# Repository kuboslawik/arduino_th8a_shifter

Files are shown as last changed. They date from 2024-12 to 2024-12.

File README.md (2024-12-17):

# Arduino TH8A Shifter Mod
Revive broken Thrustmaster TH8A shifter using Arduino and 3-axis magnetometer TLV493D module.

## Requirements
 - Arduino with USB HID capabilites, for this project Pro Micro is best suited due to small footprint
 - 3-axis magnetometer TLV493D
 - 3D printer to print custom Arduino mount
 - 4 threading screws to mount magnetometer

## Wiring
Wiring between TLV493D and Ardunio:
 - Vin -> VCC
 - GND -> GND
 - SCL -> pin 3 (SCL)
 - SDA -> pin 2 (SDA)

Wiring between TH8A pushbutton and Arduino:
 - One end should be connected to ground, and the other to pin 15 configured as pull-up.

## Code
Depending on your module, polar and azimuth values might differ, because of this, between lines 95 and 100 there is commented code which you can use to find perfect values and modify gears mapping accordingly.

For compatibility with older games, shifter gears are registerd as keyboard inputs, not as game controller buttons. Gears are coresponding to 1-8 keys in H-mode, and to +/- signs in sequential mode.

## STL Model
To mount Arduino and magnetometer, we need to print custom mount, located in 'assets/stl_part.stl' folder in repo.

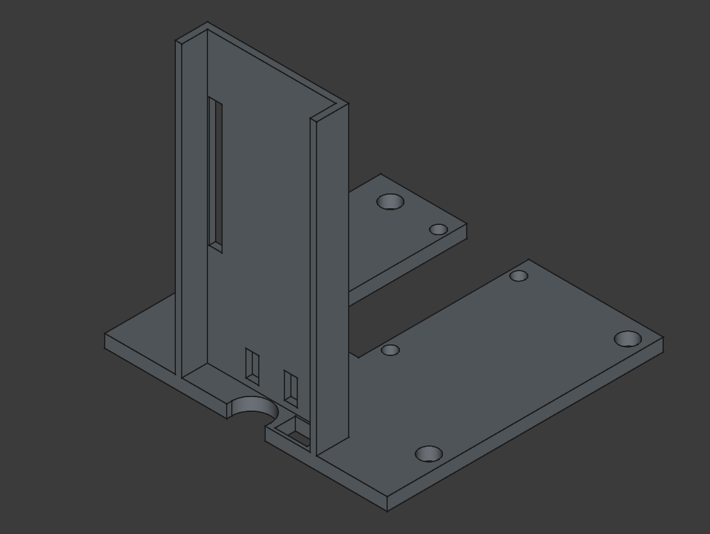
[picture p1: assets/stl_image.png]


## Assembly
Finished assembly using 4 screws from shifter and addidtional 4 threading screws to mount megnetometer module.

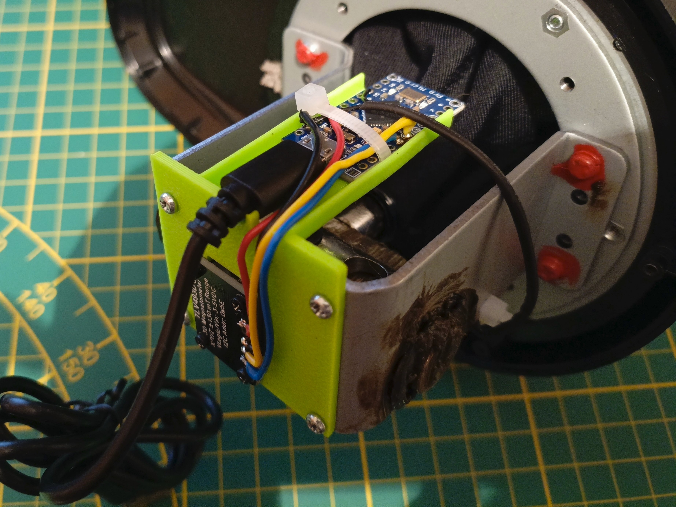
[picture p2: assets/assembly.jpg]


## HID Device Name
Normally your device will display as a generic Arduino, you can use instructions [from this issue](https://github.com/NicoHood/HID/issues/125) to modify its name. For example mine is registered as 'Arduino SA TH8A Shifter'.

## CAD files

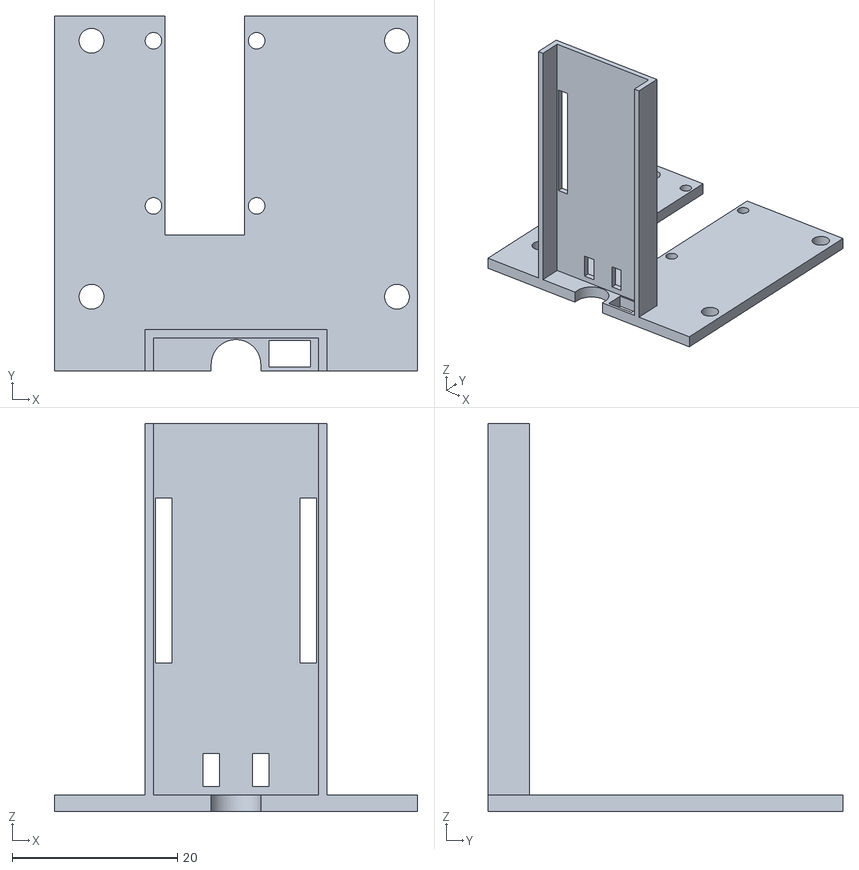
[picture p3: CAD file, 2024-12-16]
assets/stl_part.stl
44.0 x 43.0 x 47.0

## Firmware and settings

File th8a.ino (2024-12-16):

#include <Tlv493d.h>
#include <Keyboard.h>

Tlv493d Tlv493dMagnetic3DSensor = Tlv493d();

// Magnet position vairables
int azimuth = 0;
int polar = 0;

// Gear variables
int gearboxMode;
int gear = 0;
int previousGear = 0;
int lastButtonState = 0;

// Debaunce time variables
unsigned long lastDebounceTime = 0;
unsigned long debounceDelay = 20;

void setup() {
  Serial.begin(9600);
  
  Tlv493dMagnetic3DSensor.begin();
  Tlv493dMagnetic3DSensor.setAccessMode(Tlv493dMagnetic3DSensor.MASTERCONTROLLEDMODE);
  Tlv493dMagnetic3DSensor.disableTemp();

  Keyboard.begin();
  
  pinMode(15, INPUT_PULLUP);
  gearboxMode = digitalRead(15);
}

void loop() {
  delay(Tlv493dMagnetic3DSensor.getMeasurementDelay());
  Tlv493dMagnetic3DSensor.updateData();

  azimuth = Tlv493dMagnetic3DSensor.getAzimuth()*100;
  polar = Tlv493dMagnetic3DSensor.getPolar()*100;
  gearboxMode = digitalRead(15);

  if (gearboxMode == HIGH) {
    if ((azimuth >= -305 &&  azimuth <= -285) && (polar >= 65 &&  polar <= 90)) {
      gear = 49;  
    }
    else if ((azimuth >= -32 &&  azimuth <= -15) && (polar >= 80 &&  polar <= 112)) {
      gear = 50;
    }
    else if ((azimuth >= 240 &&  azimuth <= 270) && (polar >= 55 &&  polar <= 80)) {
      gear = 51;
    }
    else if ((azimuth >= 50 &&  azimuth <= 80) && (polar >= 70 &&  polar <= 90)) {
      gear = 52;
    }
    else if ((azimuth >= 195 &&  azimuth <= 225) && (polar >= 15 &&  polar <= 35)) {
      gear = 53;
    }
    else if ((azimuth >= 90 &&  azimuth <= 115) && (polar >= 25 &&  polar <= 40)) {
      gear = 54;
    }
    else if ((azimuth >= 165 &&  azimuth <= 205) && (polar >= -5 &&  polar <= 10)) {
      gear = 55;
    }
    else if ((azimuth >= 95 &&  azimuth <= 125) && (polar >= -5 &&  polar <= 15)) {
      gear = 56;
    } else {
      gear = 0;
    }
  } else {
    if (polar >= 120) {
      gear = 43;
    }
    else if (polar <= 90) {
      gear = 45;
    } else {
      gear = 0;
    }
  }

  if (gear != lastButtonState) {
    lastDebounceTime = millis();
  }

  if ((millis() - lastDebounceTime) > debounceDelay) {
    if (gear != previousGear) {
      Keyboard.releaseAll();
      previousGear = gear;
      if (gear != 0){
        Keyboard.press(gear);
      }
    }
  }

  lastButtonState = gear;

  // Calibration
  // Serial.print("Azimuth: ");
  // Serial.print(azimuth);
  // Serial.print(" ; Polar:  ");
  // Serial.println(polar);
}
